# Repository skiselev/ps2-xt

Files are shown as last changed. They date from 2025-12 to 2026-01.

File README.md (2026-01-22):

# ps2-xt
PS/2 to XT Keyboard Converter

## Overview

The PS/2 to XT project is yet another PCB design for the [AT2XT keyboard converter](https://forum.vcfed.org/index.php?threads/at2xt-keyboard-converter.26861/) developed by [Vintage Computer Federation](https://vcfed.org/) community.

It allows connecting a PS/2 keyboard to an IBM PC, IBM XT, or compatibles. An AT keyboard with an additional passive AT to PS/2 adapter, or a USB keyboard that also supports AT protocol using passive USB to PS/2 adapter, can be also used with this converter.

It was designed for several reasons:
1. Initially I couldn't find the original PCB design.
2. The original design is somewhat bulky.
3. I wanted a nice 3D printed case to go with it.
4. I wanted an easy to build and service design, with through hole components.
5. A friend asked for one...

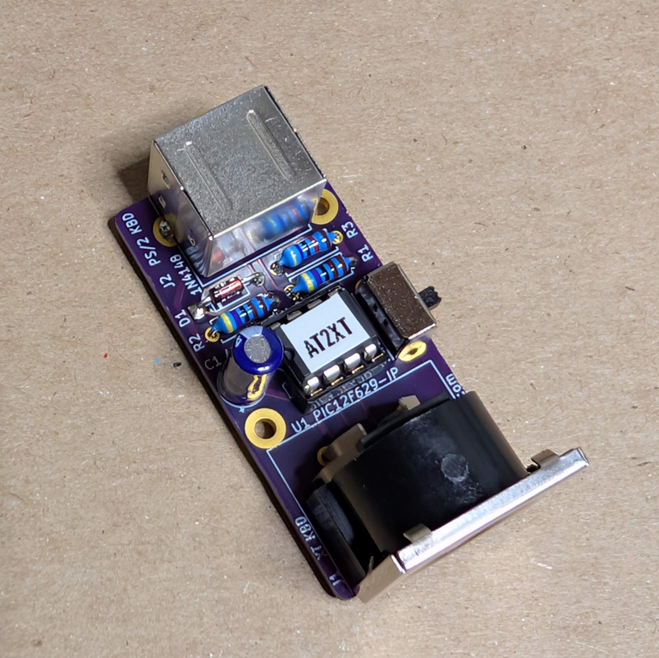
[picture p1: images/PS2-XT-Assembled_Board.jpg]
PS/2 to XT - Assembled Board


## Hardware Documentation

### Schematic and PCB Layout

* [Schematic - Version 1.0](https://github.com/skiselev/ps2-xt/blob/main/KiCad/ps2-xt-1.0-schematic.pdf)
* [PCB Layout - Version 1.0](https://github.com/skiselev/ps2-xt/blob/main/KiCad/ps2-xt-1.0-board.pdf)
* [3D printed case - Version 1.0](https://github.com/skiselev/ps2-xt/tree/main/printed)

### Assembly Instructions

1. Obtain all the parts necessary. Most parts can be purchased from Mouser. The PCB can be ordered from a PCB manufacturer of your choice using provided KiCad and Gerber files.
2. Gather tools and supplies: Soldering iron, small side cutters, needle nose pliers for forming component's leads, solder, solder wick, alcohol and lint free wipes for cleanup. You also will need a programmer to program the firmware into PIC12F629 microcontroller.
3. Start by soldering the D1 1N4148 diode. Bend the leads 90 degrees by holding each side of the diode with the pliers, and gently bending the pins down. When soldering the diode pay attention to the polarity. The black ring mark on the diode should match the white mark on the PCB silkscreen. Trim the leads using the cutters.
4. Solder R1-R3 resistors. Bend the leads 90 degrees down by gently bending them right next to the resistor's package using your fingers. Resistors don't have polarity, but note that R1 and R2 are 4.7k, while R3 is 47k. Trim the leads using the cutters.
5. Solder U1 socket. Pay attention to the socket's orientation. The notch indicating the first pin on the socket should match with the notch on the PCB silkscreen.
6. Solder SW1 switch.
7. Solder C1 capacitor. Pay attention to the polarity. The white stripe on the capacitor should match the white mark on the PCB silkscreen. Trim the leads using the cutters.
8. Solder J2 MiniDIN-6 / PS/2 connector.
9. Solder J1 DIN-5 / XT keyboard connector.
10. Check the soldering work. Clean the flux using some alcohol and wipes.
11. Program U1 PIC12F629 microcontroller and install it into the socket. Pay attention to its orientation.
12. If desired, print and assemble the 3D case using provided STL files.

### Bill of Materials

* [PS2-XT project on Mouser.com](https://www.mouser.com/Tools/Project/Share?AccessID=ace9059e87) - View and order all the components.
* [PS2-XT project on OSH Park](https://oshpark.com/shared_projects/D2kvqnaq) - View and order the PCB.

Component type     | Reference | Description                                 | Quantity | Possible sources and notes 
------------------ | --------- | ------------------------------------------- | -------- | --------------------------
PCB                |           | PS2-XT PCB - Version 1.0                    | 1        | Order from a PCB manufacturer of your choice using provided [Gerber](https://github.com/skiselev/ps2-xt/tree/main/gerber) or [KiCad](https://github.com/skiselev/ps2-xt/tree/main/KiCad) files
Integrated Circuit | U1        | PIC12F629 Microcontroller RTC, 8 pin DIP    | 1        | Mouser [579-PIC12F629IP](https://www.mouser.com/ProductDetail/579-PIC12F629IP)
IC Socket          | U2        | 8 pin DIP                                   | 1        | Mouser [737-ICS-308-T](https://www.mouser.com/ProductDetail/737-ICS-308-T)
Diode              | D1        | 1N4148                                      | 1        | Mouser [512-1N4148TA](https://www.mouser.com/ProductDetail/512-1N4148TA)
Capacitor          | C1        | 47 pF, 25V, electrolythic, 2 mm pitch       | 1        | Mouser [710-860040472001](https://www.mouser.com/ProductDetail/710-860040472001)
Resistor           | R1 - R2   | 4.7 kohm, 0.25 W, 1% tolerance, axial       | 2        | Mouser [603-MFR-25FRF52-4K7](https://www.mouser.com/ProductDetail/603-MFR-25FRF52-4K7)
Resistor           | R3        | 47 kohm, 0.25 W, 1% tolerance, axial        | 1        | Mouser [603-MFR-25FRF52-47K](https://www.mouser.com/ProductDetail/603-MFR-25FRF52-47K)
Connector          | J1        | DIN-5 socket                                | 1        | Mouser [806-KCDX-5S-S2](https://www.mouser.com/ProductDetail/806-KCDX-5S-S2)
Connector          | J2        | MiniDin-6 socket                            | 1        | Mouser [806-KMDGX-6S-BS](https://www.mouser.com/ProductDetail/806-KMDGX-6S-BS)
Switch             | SW1       | Slider SPDT switch                          | 1        | Mouser [179-SLW8645872ARAND](https://www.mouser.com/ProductDetail/179-SLW8645872ARAND)

## Additional Photos

### Complete PS/2 to XT in a Case

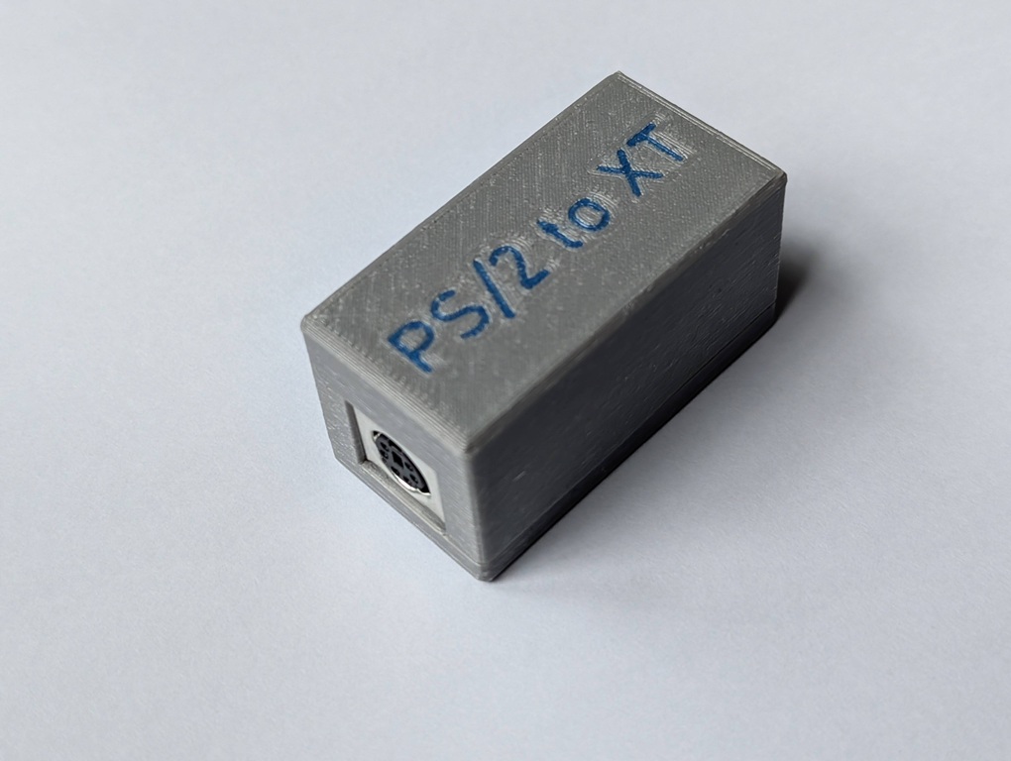
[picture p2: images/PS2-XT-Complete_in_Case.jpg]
PS/2 to XT - Complete in a Case


### Both Sides of the Assembled Boards

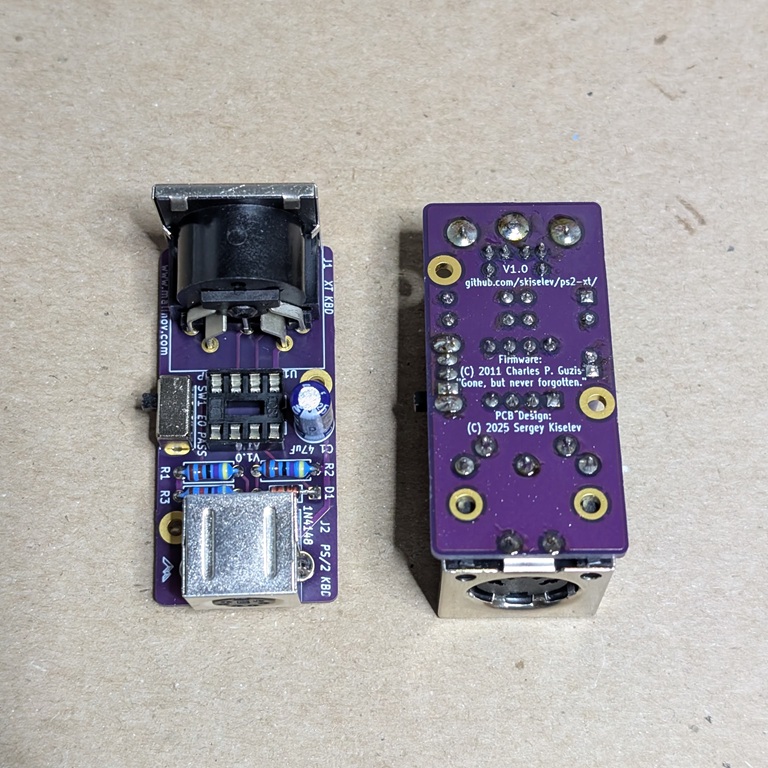
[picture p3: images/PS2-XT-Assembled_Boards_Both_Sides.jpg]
PS/2 to XT - Both Sides of the Assembled Boards


## Release Notes

### Changes

### Known Issues

* Version 1.0
  * No known issues

### Wishlist
* Use smaller footprint for the DIN-5. Reduce the PCB size.

## Red Tape

### Licensing

The hardware design itself, including schematic, PCB layout design, and 3D printed case design files are licensed under the strongly-reciprocal variant of [CERN Open Hardware Licence version 2](license-cern_ohl_s_v2.txt). Documentation, including this file, is licensed under the [Creative Commons Attribution-ShareAlike 4.0 International License](license-cc-by-sa-4.0.txt).

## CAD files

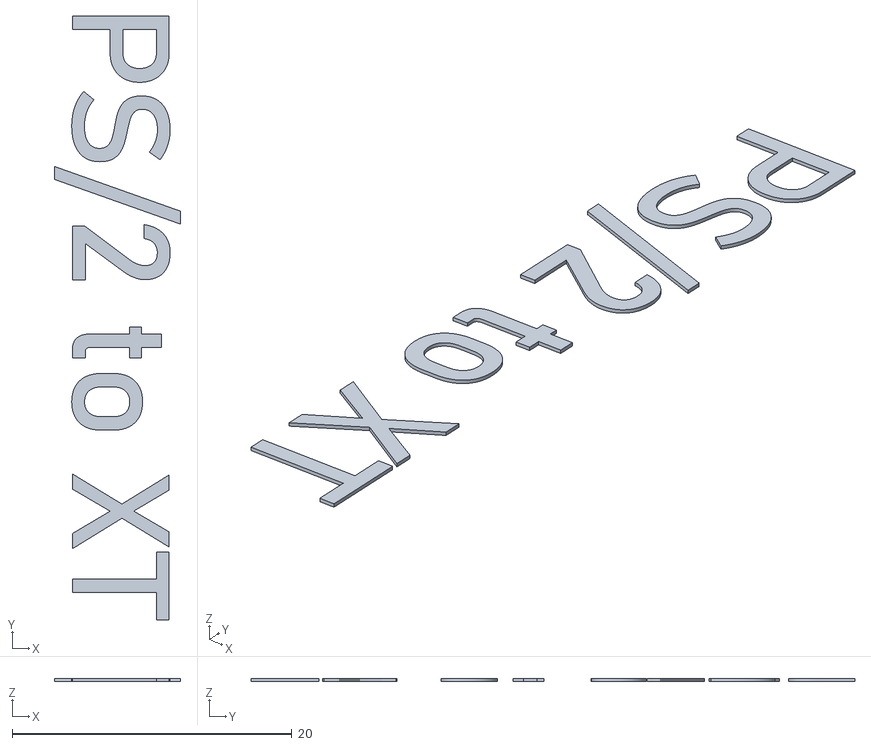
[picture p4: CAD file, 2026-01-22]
printed/ps2-xt_label.stl
9.03 x 43.2 x 0.2

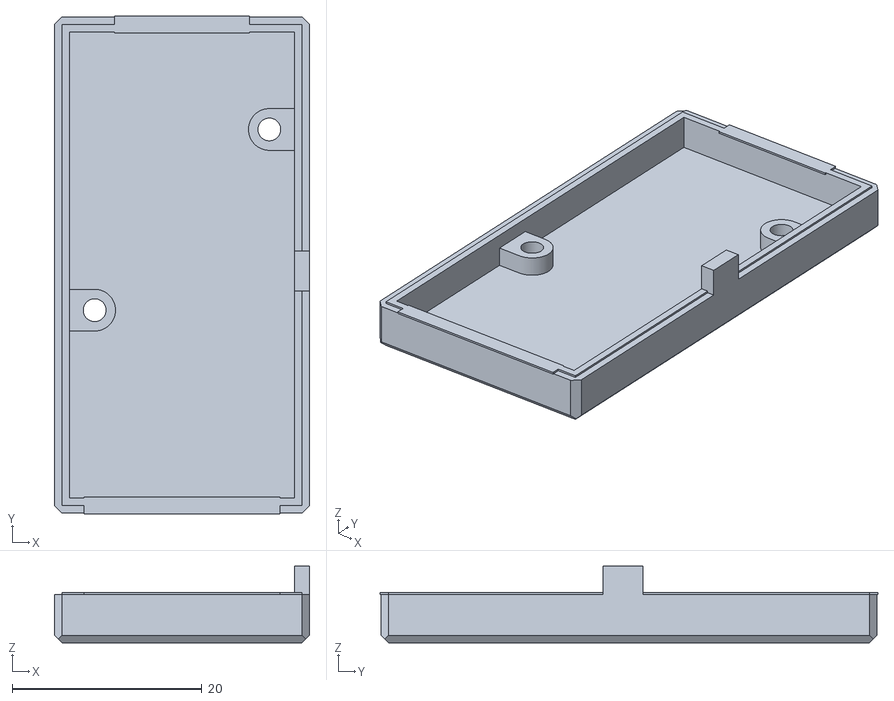
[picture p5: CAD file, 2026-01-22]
printed/ps2-xt_bottom.stl
26.9 x 52.5 x 8.10

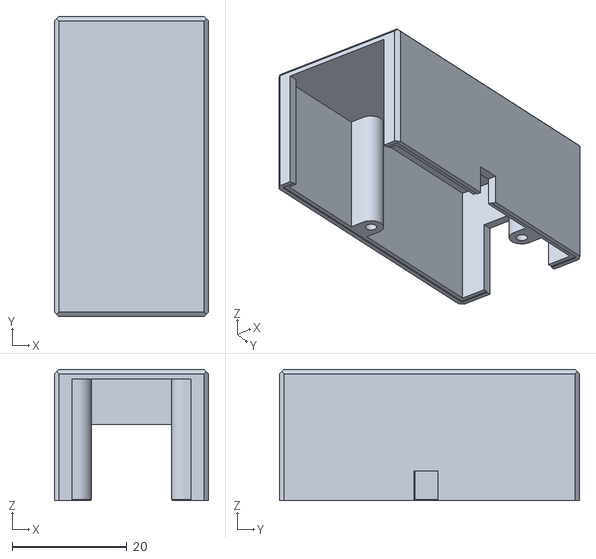
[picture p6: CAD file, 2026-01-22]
printed/ps2-xt_top_with_label.stl
26.9 x 52.3 x 22.9

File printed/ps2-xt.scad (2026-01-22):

case_thickness=1.6;
tolerance=0.1;
$fn=72;

board_width=0.925*25.4;
board_length=1.925*25.4;
component_height=21.0; // DIN-5 connector
board_thickness=1.6; // check if it's correct
component_leads=2; // component leads sticking out on the bottom side of the PCB
din5_width=20.5;
din5_height=21.0;
minidin6_width=14;
minidin6_height=13;
switch_width=4;
switch_height=2;
switch_y=board_length/2-0.9875*25.4;
switch_z=3.9;
standoff_radius=2.2;
standoff_width=tolerance+0.1*25.4;
standoff1_x=-board_width/2+0.825*25.4;
standoff1_y=board_length/2-0.4*25.4;
standoff2_x=-board_width/2+0.1*25.4;
standoff2_y=board_length/2-1.15*25.4;
// #2-56 UNC screw... Pretty close to M2
screw_thread=2;
screw_diameter=2.4; // 0.086*25.4 =2.1844 mm
screw_head_height=0.051*25.4;
screw_head_diameter=0.162*25.4;
text_thickness=0.2; // one 3D printer layer


case_width=board_width+tolerance*2;
case_length=board_length+tolerance*2;
case_height=component_height+board_thickness+component_leads+tolerance*2;
case_bottom_height=board_thickness+component_leads+tolerance;
case_top_height=component_height+tolerance;
overlap_width=0.8;
overlap_height=0.2;
top_bottom_overlap=0.4;

// comment out functions below to draw specific parts only
case_top();
color("cyan") case_bottom();
translate([0,0,case_top_height+case_thickness-text_thickness]) {
    color("blue") case_label();
}

module case_label()
{
    rotate([0,0,-90]) {
        linear_extrude(text_thickness) {
            text("PS/2 to XT",size=7,font = "Bahnschrift",halign="center",valign= "center");
        }
    }
}

// axis orientation: X-Y - bottom/top, X-Z - front/back, Y-Z - left/right
module case_top()
{        
    // move above X-Y plane
    translate([0,0,(case_top_height+case_thickness)/2]) {
        difference() {
            union() {
                color("silver") {
                    translate([0,0,-overlap_height/2]) rotate([180,0,0]) {
                        case_shell(case_width,case_length,case_top_height+overlap_height,case_thickness,case_thickness/2);
                    }
                    // standoff - far / righ
                    translate([standoff1_x,standoff1_y,-case_thickness/2]) {
                        cylinder(h=case_top_height,r=standoff_radius,center=true);
                        translate([standoff_width/2,0,0]) {
                            cube([standoff_width,standoff_radius*2,case_top_height],center=true);
                        }
                    }
                    // standoff - near / left
                    translate([standoff2_x,standoff2_y,-case_thickness/2]) {
                        cylinder(h=case_top_height,r=standoff_radius,center=true);
                        translate([-standoff_width/2,0,0]) {
                            cube([standoff_width,standoff_radius*2,case_top_height],center=true);
                        }
                    }
                }
            }
            // MiniDIN-6 cutout
            translate([0,(case_length+case_thickness)/2,(minidin6_height-case_top_height-case_thickness-overlap_height)/2]) {
                cube([minidin6_width+tolerance*2,case_thickness+tolerance*2,minidin6_height+overlap_height+tolerance],center=true);
            }
            // DIN-5 cutout
            translate([0,-(case_length+case_thickness)/2,(din5_height-case_top_height-case_thickness-overlap_height)/2]) {
                cube([din5_width+tolerance*2,case_thickness+tolerance*2,din5_height+overlap_height+tolerance],center=true);
            }
            // switch cutout
            translate([(case_width+case_thickness)/2,switch_y,(switch_height/2+tolerance+switch_z-case_top_height-case_thickness-top_bottom_overlap)/2]) {
                cube([case_thickness+tolerance*2,switch_width+tolerance*2,switch_height/2+top_bottom_overlap+tolerance+switch_z],center=true);
            }
            // screw hole - far / right
            translate([standoff1_x,standoff1_y,-case_thickness/2-tolerance]) {
                cylinder(h=case_top_height,d=screw_thread,center=true);
            }
            // screw hole - near / left
            translate([standoff2_x,standoff2_y,-case_thickness/2-tolerance]) {
                cylinder(h=case_top_height,d=screw_thread,center=true);
            }
            // label
            translate([0,0,(case_top_height+case_thickness)/2-text_thickness]) {
                case_label();
            }
            // overlap cut-out
            translate([0,0,-(case_top_height+case_thickness+overlap_height+tolerance)/2]) {
                cube([case_width+overlap_width*2,case_length+overlap_width*2,overlap_height+tolerance],center=true);
            }
        }
    }
}

module case_bottom()
{
    // move below X-Y plane
    translate([0,0,-(case_bottom_height+case_thickness)/2]) {
        difference() {
            union() {
                case_shell(case_width,case_length,case_bottom_height,case_thickness,case_thickness/2);
                // standoff - far / righ
                translate([standoff1_x,standoff1_y,(case_bottom_height-case_thickness-board_thickness)/2-tolerance*2]) {
                    cylinder(h=case_bottom_height-board_thickness,r=standoff_radius,center=true);
                    translate([standoff_width/2,0,0]) {
                        cube([standoff_width,standoff_radius*2,case_bottom_height-board_thickness],center=true);
                    }
                }
                // standoff - near / left
                translate([standoff2_x,standoff2_y,(case_bottom_height-case_thickness-board_thickness)/2-tolerance*2]) {
                    cylinder(h=case_bottom_height-board_thickness,r=standoff_radius,center=true);
                    translate([-standoff_width/2,0,0]) {
                        cube([standoff_width,standoff_radius*2,case_bottom_height-board_thickness],center=true);
                    }
                }
            }
            // screw hole - far / right
            translate([standoff1_x,standoff1_y,-board_thickness/2]) {
                cylinder(h=case_bottom_height+case_thickness-board_thickness+tolerance*2,d=screw_diameter,center=true);
            }

            //screw head countersink hole
            translate([standoff1_x,standoff1_y,-(case_bottom_height+case_thickness-screw_head_height)/2]) {
                cylinder(h=screw_head_height,d1=screw_head_diameter,d2=screw_diameter,center=true);
            }

            // screw hole - near / left
            translate([standoff2_x,standoff2_y,-board_thickness/2]) {
                cylinder(h=case_bottom_height+case_thickness-board_thickness+tolerance*2,d=screw_diameter,center=true);
            }
            
            //screw head countersink hole
            translate([standoff2_x,standoff2_y,-(case_bottom_height+case_thickness-screw_head_height)/2]) {
                cylinder(h=screw_head_height,d1=screw_head_diameter,d2=screw_diameter,center=true);
            }
            // overlap cut-out
            // right
            translate([(case_width+case_thickness+overlap_width)/2,0,(case_bottom_height+case_thickness-overlap_height+tolerance)/2]) {
                cube([overlap_width,case_length+case_thickness*2,overlap_height+tolerance],center=true);
            }         
            // left
            translate([-(case_width+case_thickness+overlap_width)/2,0,(case_bottom_height+case_thickness-overlap_height+tolerance)/2]) {
                cube([overlap_width,case_length+case_thickness*2,overlap_height+tolerance],center=true);
            }
            // far
            translate([0,(case_length+case_thickness+overlap_width)/2,(case_bottom_height+case_thickness-overlap_height+tolerance)/2]) {
                cube([case_width+case_thickness*2,overlap_width,overlap_height+tolerance],center=true);
            }
            // near
            translate([0,-(case_length+case_thickness+overlap_width)/2,(case_bottom_height+case_thickness-overlap_height+tolerance)/2]) {
                cube([case_width+case_thickness*2,overlap_width,overlap_height+tolerance],center=true);
            }
        }
        // switch cutout cover
        translate([(case_width+case_thickness)/2,switch_y,(case_bottom_height+case_thickness+switch_z-switch_height/2-overlap_height-tolerance)/2]) {
            cube([case_thickness,switch_width+tolerance*2,switch_z-switch_height/2+overlap_height-tolerance],center=true);
        }
        // MiniDIN-6 cutout cover
        translate([0,(case_length+case_thickness)/2,(case_bottom_height+case_thickness-overlap_height)/2]) {
            cube([minidin6_width+tolerance*2,case_thickness+tolerance*2,overlap_height],center=true);
        }
        // DIN-5 cutout cover
        translate([0,-(case_length+case_thickness)/2,(case_bottom_height+case_thickness-overlap_height)/2]) {
            cube([din5_width+tolerance*2,case_thickness+tolerance*2,overlap_height],center=true);
        }
    }
}
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

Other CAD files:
printed/ps2-xt_top.stl

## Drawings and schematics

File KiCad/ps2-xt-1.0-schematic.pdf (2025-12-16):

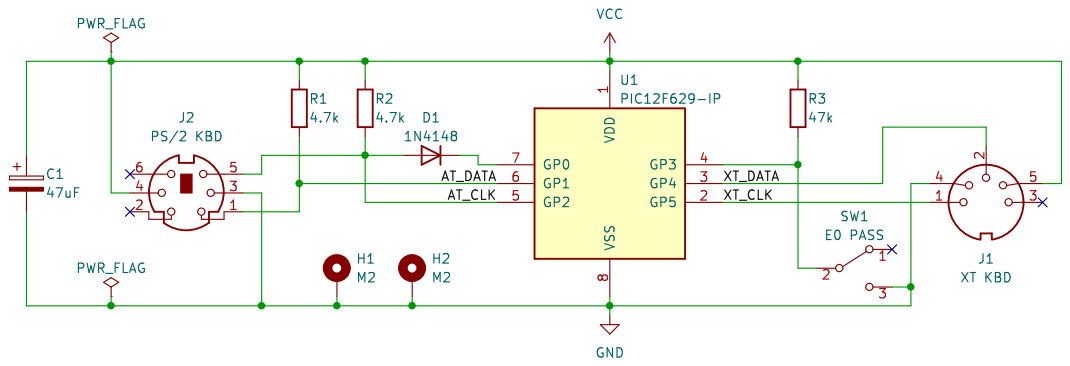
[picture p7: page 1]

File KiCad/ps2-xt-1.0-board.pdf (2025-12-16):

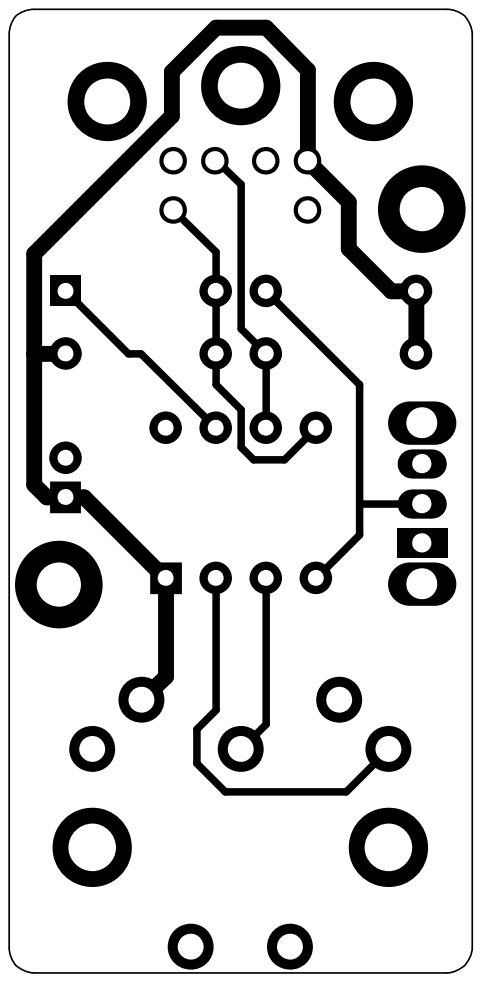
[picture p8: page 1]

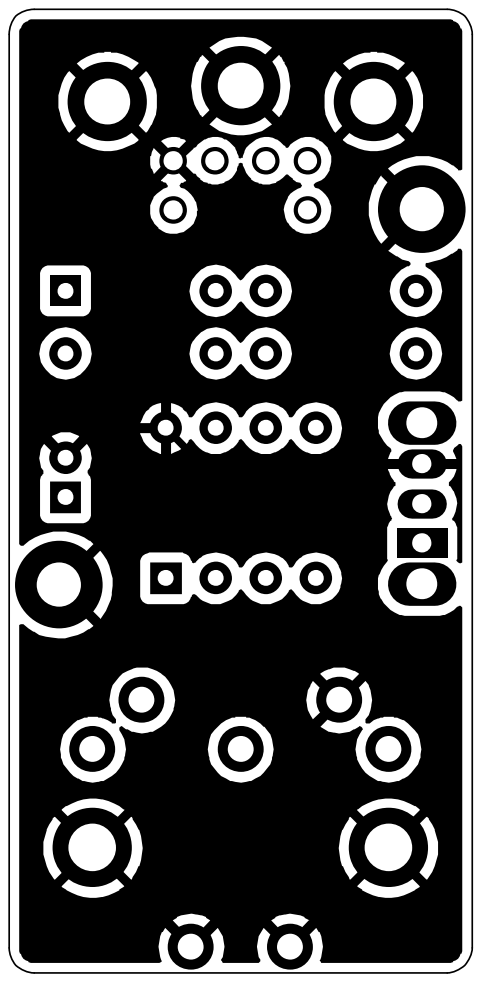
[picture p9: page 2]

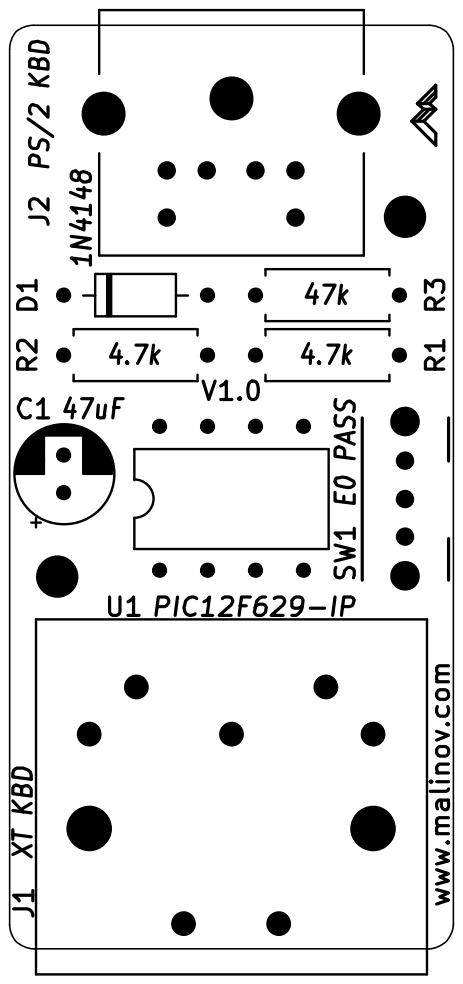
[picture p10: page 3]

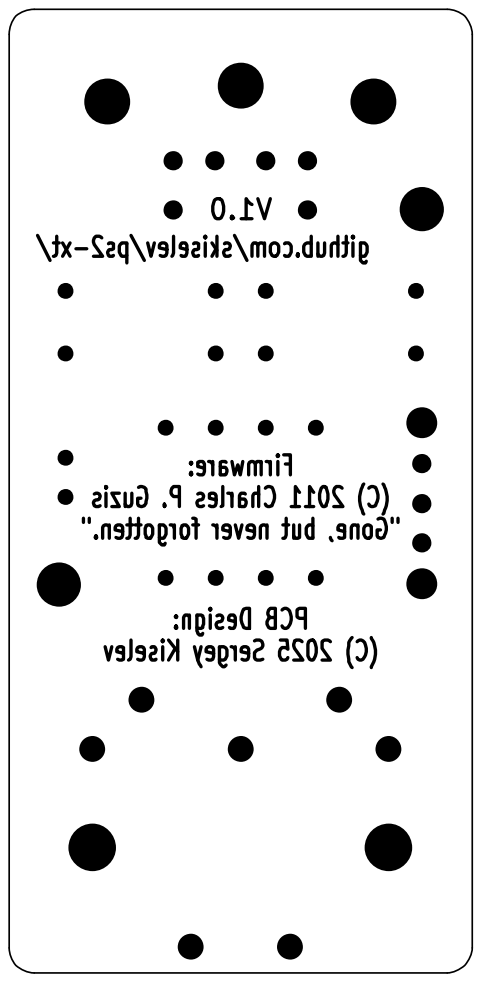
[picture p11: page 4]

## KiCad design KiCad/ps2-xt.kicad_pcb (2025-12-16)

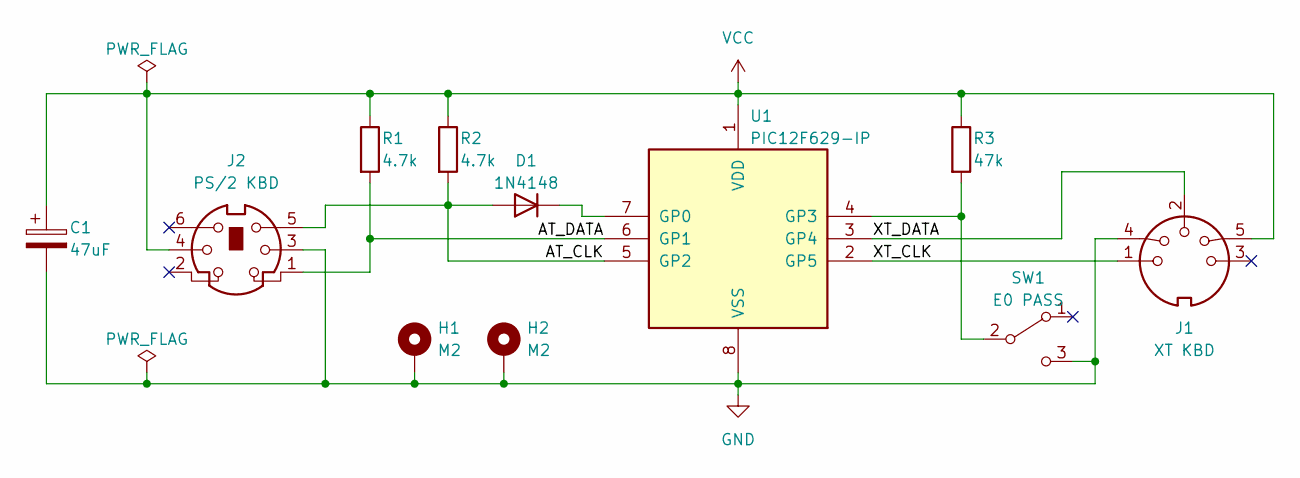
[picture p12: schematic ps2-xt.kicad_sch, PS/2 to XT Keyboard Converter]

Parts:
C1: 47uF; CP_Radial_D5.0mm_P2.00mm
D1: 1N4148; D_DO-35_SOD27_P7.62mm_Horizontal
H1, H2: M2; MountingHole_2.2mm_M2_Pad
J1: XT KBD; Conn_DIN_5pin
J2: PS/2 KBD; Conn_Mini_DIN_6pin
R1, R2: 4.7k; R_Axial_DIN0207_L6.3mm_D2.5mm_P7.62mm_Horizontal
R3: 47k; R_Axial_DIN0207_L6.3mm_D2.5mm_P7.62mm_Horizontal
SW1: E0 PASS; SW_CuK_OS102011MA1QN1_SPDT_Angled
U1: PIC12F629-IP; DIP-8_W7.62mm

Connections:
/AT_CLK: D1.2 (A), J2.5, R2.2, U1.5 (GP2)
/AT_DATA: J2.1, R1.2, U1.6 (GP1)
/XT_CLK: J1.1, U1.2 (GP5)
/XT_DATA: J1.2, U1.3 (GP4)
GND: C1.2, H1.1, H2.1, J1.0, J1.4, J1.~, J2.3, J2.~, SW1.3 (C), U1.8 (VSS)
unnamed: D1.1 (K), U1.7 (GP0)
unnamed: R3.2, SW1.2 (B), U1.4 (GP3)
VCC: C1.1, J1.5, J2.4, R1.1, R2.1, R3.1, U1.1 (VDD)

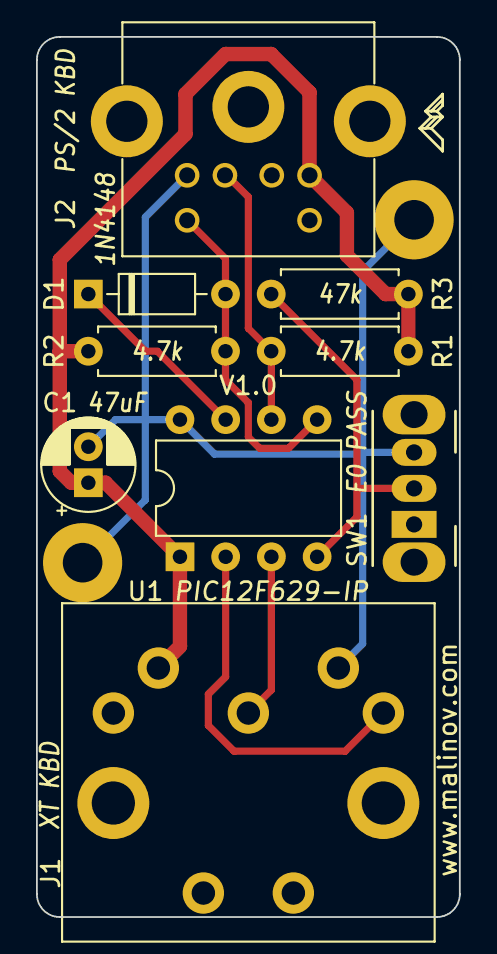
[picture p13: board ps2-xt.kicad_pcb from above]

Board: 2 copper layers, 23.5 x 48.9 mm, 11 parts (0 on the bottom side), 8 nets.

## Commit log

2025-12-16 Add KiCad and Gerber files for V1.0
    [ps2-xt-B_Cu.gbr, ps2-xt-B_Mask.gbr, ps2-xt-B_Paste.gbr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]
2026-01-22 Add 3D printed case
    [ps2-xt.scad, ps2-xt_bottom.stl, ps2-xt_label.stl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]
2026-01-22 README: Add pictures and 3D printed case link
2026-01-22 Add a photo of both sides of the board
2026-01-22 README: Add photo of both sides of the board

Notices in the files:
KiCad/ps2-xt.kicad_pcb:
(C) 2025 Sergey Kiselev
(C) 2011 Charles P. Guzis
